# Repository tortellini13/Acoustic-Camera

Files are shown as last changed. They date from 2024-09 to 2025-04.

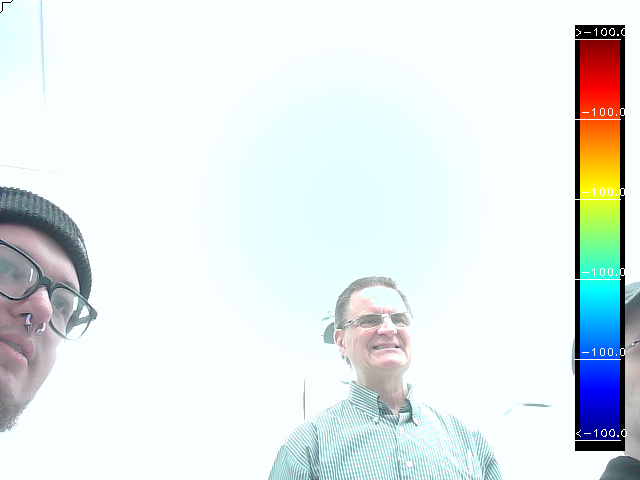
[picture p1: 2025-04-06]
Captures/image_20250403122323.png

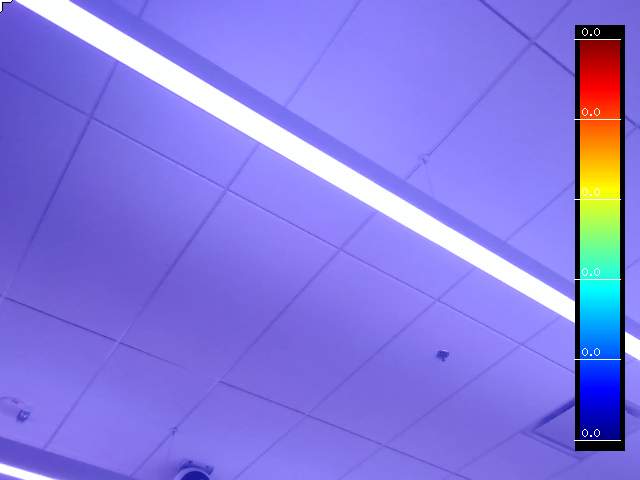
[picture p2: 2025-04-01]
Captures/image_20250327161520.png

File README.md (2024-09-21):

# About the Project
[*Click here to skip to the build*](#the-build)

### The Team
*About us and uhart*  
@us  
*Why did we make this*

### The Project
*What is an acoustical camera*

# How to Build

## Background
We have come across numerous open source projects that assume you know how to do certain basic things going into the project. We aim to eliminate as much of that barrier to entry as possible in the documentation for this project. You should be able to make this project for yourself from scratch with only the skills stated below.

### Skills Required
- thing
- thing

### Dependencies
- thing
- thing

## The Build
### 1. Hardware Required
1. 
2. 
3. 

### 2. Setting Up the Pi

### 3. 3-D Printing

> [!TIP]
> this is a test to see if Tip works.

## Contributing to the Project
This section will help you contribute to the project if you would like to. A bit more prior experience is needed to contribute.

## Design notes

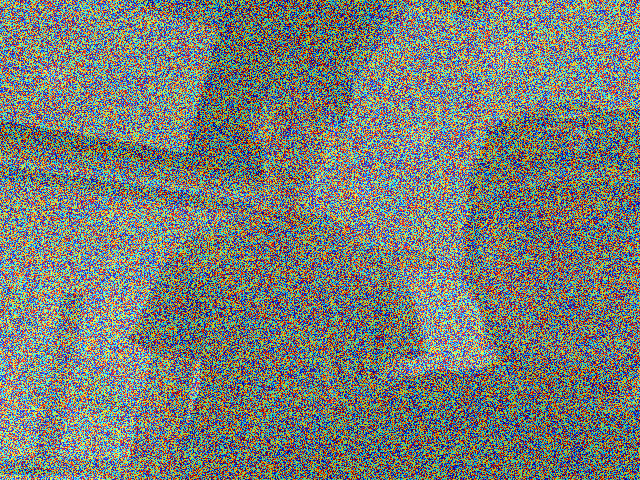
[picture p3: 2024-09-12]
Other/Heat Map Overlay_screenshot_12.09.2024.png

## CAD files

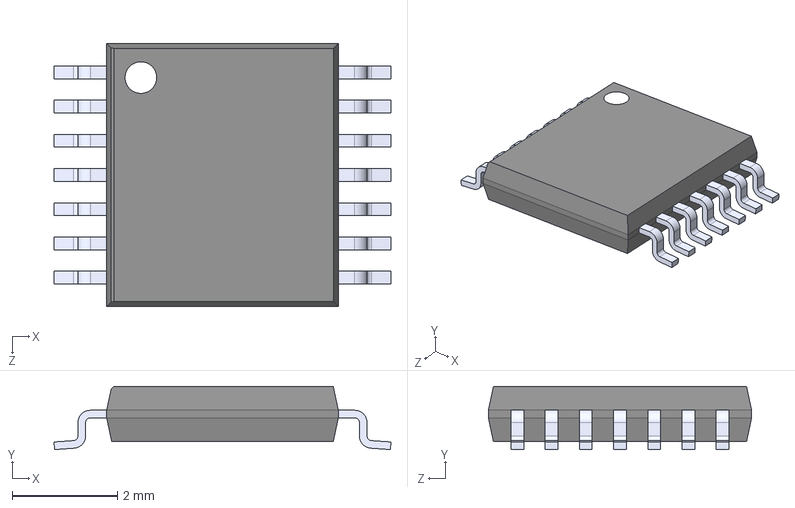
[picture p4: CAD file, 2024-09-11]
Microphone Array CAD/Electrical/Parts (Datasheets, KiCad Libs)/74LCX125MTCX/74LCX125MTCX.step
6.40 x 1.20 x 5.00 mm

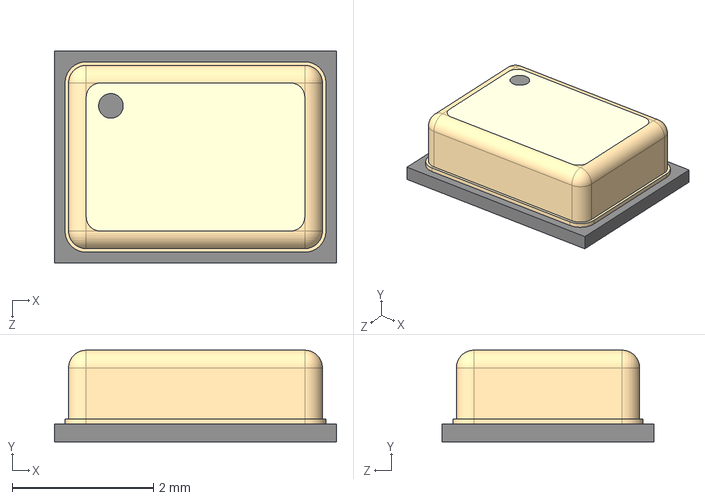
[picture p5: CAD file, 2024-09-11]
Microphone Array CAD/Electrical/Parts (Datasheets, KiCad Libs)/IM69D120V01XTSA1/IM69D120V01XTSA1.step
4.00 x 1.30 x 3.00 mm

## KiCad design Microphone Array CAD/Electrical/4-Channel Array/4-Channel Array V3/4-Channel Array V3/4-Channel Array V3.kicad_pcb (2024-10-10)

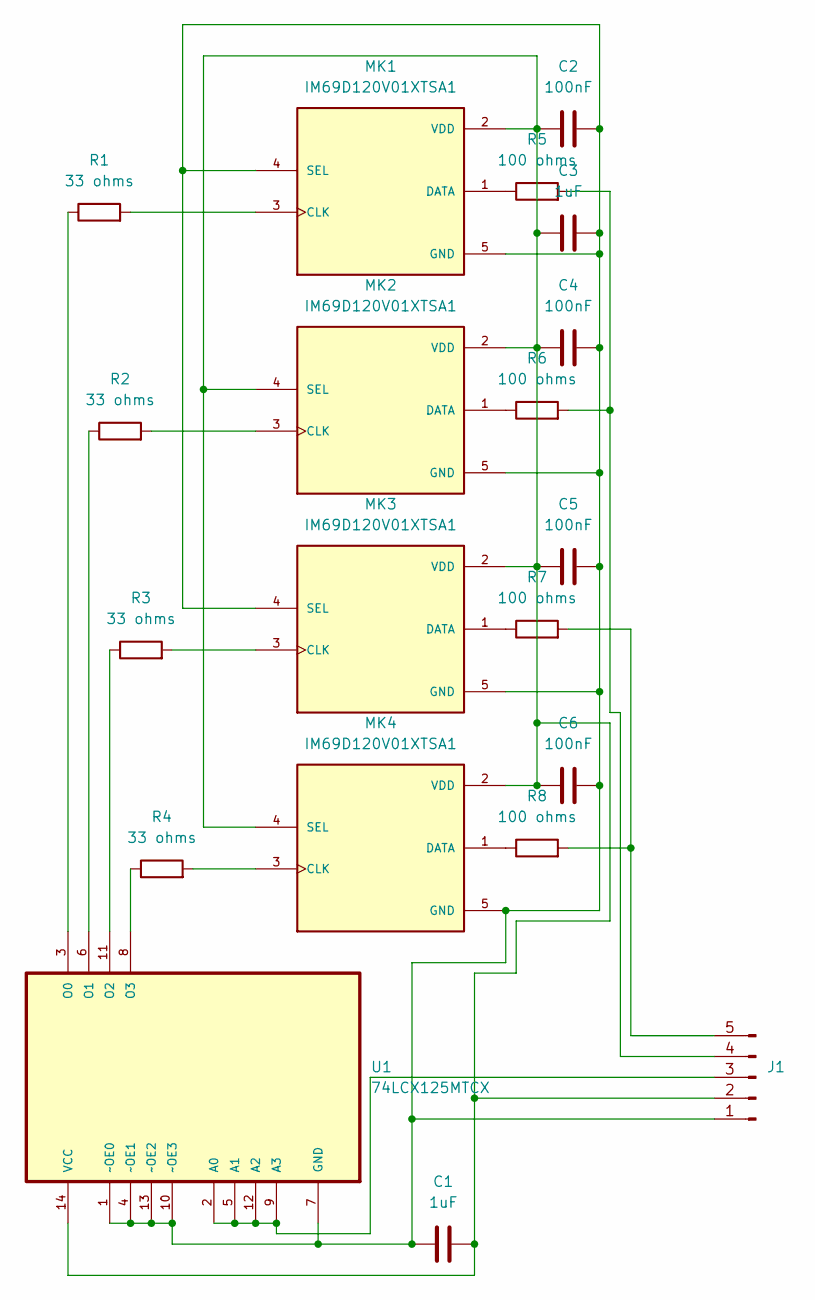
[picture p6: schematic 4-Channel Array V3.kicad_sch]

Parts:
C1, C3: 1uF; R_0603_1608Metric
C2, C4, C5, C6: 100nF; C_0402_1005Metric
J1: Conn_01x05_Pin; JST_XH_B5B-XH-A_1x05_P2.50mm_Vertical
MK1, MK2, MK3, MK4: IM69D120V01XTSA1; XDCR_IM69D120V01XTSA1; PARTREV 1.0
R1, R2, R3, R4: 33 ohms; R_0603_1608Metric
R5, R6, R7, R8: 100 ohms; R_0603_1608Metric
U1: 74LCX125MTCX; SOP65P640X120-14N; MPN 74LCX125MTCX

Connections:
unnamed: C1.1, C2.2, C3.2, C4.2, C5.2, C6.2, J1.1, MK1.4 (SEL), MK1.5 (GND), MK2.5 (GND), MK3.4 (SEL), MK3.5 (GND), MK4.5 (GND), U1.1 (~OE0), U1.4 (~OE1), U1.7 (GND), U1.10 (~OE3), U1.13 (~OE2)
unnamed: C1.2, C2.1, C3.1, C4.1, C5.1, C6.1, J1.2, MK1.2 (VDD), MK2.2 (VDD), MK2.4 (SEL), MK3.2 (VDD), MK4.2 (VDD), MK4.4 (SEL), U1.14 (VCC)
unnamed: J1.3, U1.2 (A0), U1.5 (A1), U1.9 (A3), U1.12 (A2)
unnamed: J1.4, R5.2, R6.2
unnamed: J1.5, R7.2, R8.2
unnamed: MK1.3 (CLK), R1.2
unnamed: MK1.1 (DATA), R5.1
unnamed: MK2.3 (CLK), R2.2
unnamed: MK2.1 (DATA), R6.1
unnamed: MK3.3 (CLK), R3.2
unnamed: MK3.1 (DATA), R7.1
unnamed: MK4.3 (CLK), R4.2
unnamed: MK4.1 (DATA), R8.1
unnamed: R1.1, U1.3 (O0)
unnamed: R2.1, U1.6 (O1)
unnamed: R3.1, U1.11 (O2)
unnamed: R4.1, U1.8 (O3)

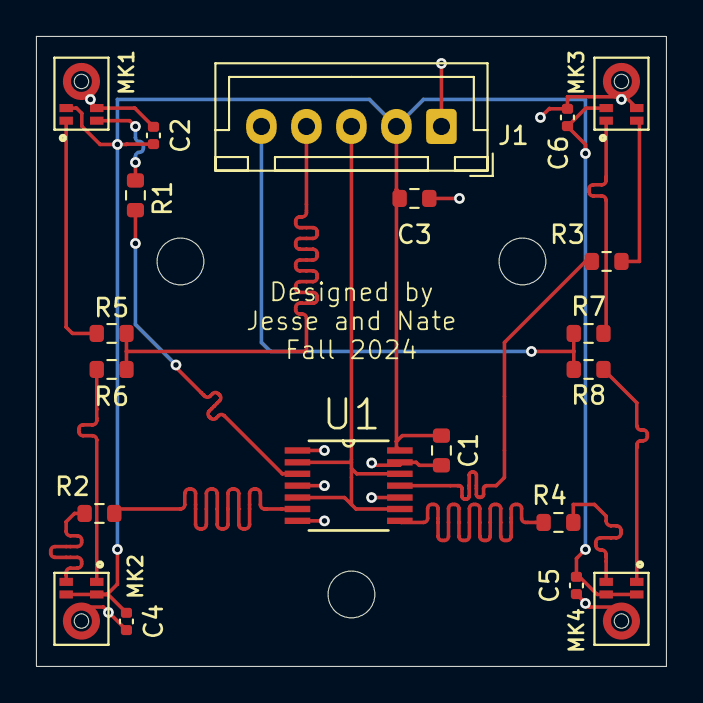
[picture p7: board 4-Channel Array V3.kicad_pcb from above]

Board: 2 copper layers, 35.0 x 35.0 mm, 20 parts (0 on the bottom side), 17 nets.

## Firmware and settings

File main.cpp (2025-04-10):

// Libraries
#include <opencv2/opencv.hpp>
#include <iostream>
#include <vector>
#include <ctime>
#include <chrono>
#include <iomanip>

#include "PARAMS.h"
#include "ALSA.h"
#include "Beamform.h"
#include "Video.h"
#include "Timer.h"
#include "wav.h"


using namespace std;

CONFIG configs(NUM_INT_CONFIGS, NUM_FLOAT_CONFIGS, NUM_BOOL_CONFIGS, NUM_STRING_CONFIGS);

int main()
{

    Mat frame;

    //=====================================================================================

    // Initialize ALSA and Beamform
    #ifdef ENABLE_AUDIO
    #ifdef ENABLE_ALSA
    ALSA ALSA(AUDIO_DEVICE_NAME, M_AMOUNT, N_AMOUNT, SAMPLE_RATE, FFT_SIZE);
    #endif
    beamform beamform(FFT_SIZE, SAMPLE_RATE, M_AMOUNT, N_AMOUNT, NUM_TAPS,
                      MIC_SPACING, 343.0f,
                      MIN_THETA, MAX_THETA, STEP_THETA, NUM_THETA,
                      MIN_PHI, MAX_PHI, STEP_PHI, NUM_PHI);
    #endif

    // Initialize video
    #ifdef ENABLE_VIDEO
    video video(RESOLUTION_WIDTH, RESOLUTION_HEIGHT, FRAME_RATE);
    //VideoCapture cap(0); // Open default camera
    #endif

    //=====================================================================================

    // Timer for testing
    timer test("Test");

    // Arrays to store data
    array3D<float> audio_data_buffer_1(M_AMOUNT, N_AMOUNT, FFT_SIZE);
    array3D<float> audio_data_buffer_2(M_AMOUNT, N_AMOUNT, FFT_SIZE);
    cv::Mat processed_data(NUM_THETA, NUM_PHI, CV_32FC1, cv::Scalar(0));

    // Clear buffers
    for (int m = 0; m < audio_data_buffer_1.dim_1; m++)
    {
        for (int n = 0; n < audio_data_buffer_1.dim_2; n++)
        {
            for (int b = 0; b < audio_data_buffer_1.dim_3; b++)
            {
                audio_data_buffer_1.at(m, n, b) = 0.0f;
                audio_data_buffer_2.at(m, n, b) = 0.0f;
            } // end b
        } // end n
    } // end m

    // Send configuration to ALSA and start recording audio
    #ifdef ENABLE_AUDIO
    #ifdef ENABLE_ALSA
    ALSA.setup();
    ALSA.start();
    #endif
    // cout << "Audio setup complete.\n"; 

    beamform.setup();
    // cout << "Beamform setup complete.\n";

    #ifdef ENABLE_WAV
    WAV WAV;
    WAV.setup("test1k.wav");
    #endif
    #endif
    // Start video capture
    #ifdef ENABLE_VIDEO 
    video.startCapture();
    cout << "Video setup complete.\n";
    #endif
 
    //=====================================================================================

    cout << "Starting main loop.\n";
    while(1)
    {
        
        test.start();
        // Copy data from ring buffer and process beamforming
        #ifdef ENABLE_AUDIO
        #ifdef ENABLE_ALSA
        ALSA.copyRingBuffer(audio_data_buffer_1, audio_data_buffer_2);
        #endif
        // audio_data_buffer_1.print_layer(100);
        #ifdef ENABLE_WAV
        WAV.readWAV(audio_data_buffer_1, audio_data_buffer_2);
        #endif

        beamform.processData(processed_data, 19, 24, POST_dBFS, audio_data_buffer_1, audio_data_buffer_2);
        // cout << "End of processData\n";

        
        #endif
        
        // Generate heatmap and ui then display the frame
        int pcm_error = 0;
        #ifdef ENABLE_VIDEO
        // if (waitKey(1) >= 0) break;
        #ifdef ENABLE_AUDIO
        #ifdef ENABLE_ALSA
        int pcm_error = ALSA.pcm_error;
        #endif
        #endif
        if (video.processFrame(processed_data, pcm_error) == false) break;
        //if (waitKey(1) >= 0) break;
        #endif

        test.end();

        double time = test.time(false);
        double fps = 1 / time;
        // cout << "FPS: " << fps << "\n";

        // test.print();
        // test.print_avg(AVG_SAMPLES);

    } // end loop

    //=====================================================================================

    // Clean up and exit
    #ifdef ENABLE_AUDIO
    #ifdef ENABLE_ALSA
    ALSA.stop();
    #endif
    #endif

    #ifdef ENABLE_VIDEO
    video.stopCapture();
    #endif
 
    return 0;
} // end main

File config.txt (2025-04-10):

=======
third_band_value=25
save_path=/home/pi/Desktop/Acoustic-Camera/Captures
quality=2
full_range=true
imgui_alpha=0.480000
<<<<<<< HEAD
imgui_clamp_max=0
imgui_clamp_min=-93
=======
imgui_clamp_max=20
imgui_clamp_min=-500
>>>>>>> 6685142 (trying phased array again)
heatmap=COLORMAP_JET
hidden_menu=false
mark_max_mag_state=true
octave_bands=false
color_scale_state=true
heat_map_state=true
octave_band_value=6
<<<<<<< HEAD
imgui_threshold=-89
=======
imgui_threshold=-500
>>>>>>> 6685142 (trying phased array again)
static_state=false
data_clamp_state=true
threshold_state=true
auto_save_state=true
record_state=false
capture_image_state=false
random_state=false
options_menu=false

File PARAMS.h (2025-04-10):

#ifndef PARAMS
#define PARAMS

#include "Structs.h"

// Mic channels
#define M_AMOUNT 4 // Amount of mics in the M direction
#define N_AMOUNT 4 // Amount of mics in the N direction
#define MIC_SPACING 0.030f // Meters
const int NUM_CHANNELS = (M_AMOUNT * N_AMOUNT); // Total number of channels
const int CHANNEL_ORDER[M_AMOUNT][N_AMOUNT] =
{
    {10, 8,  2, 0},
    {11, 9,  3, 1},
    {14, 12, 6, 4},
    {15, 13, 7, 5}
};
#define MIC_GAIN 1.0f

// Angles
#define MIN_THETA -30
#define MAX_THETA  30
#define STEP_THETA 3 // 2 is correct
// #define MIN_THETA -90
// #define MAX_THETA 90
// #define STEP_THETA 10
const int NUM_THETA = ((MAX_THETA - MIN_THETA) / STEP_THETA) + 1;

#define MIN_PHI -18
#define MAX_PHI  18
#define STEP_PHI 2 // 1 is correct
// #define MIN_PHI -90
// #define MAX_PHI 90
// #define STEP_PHI 10
const int NUM_PHI = ((MAX_PHI - MIN_PHI) / STEP_PHI) + 1;

#define NUM_TAPS 5

// FFT
#define FFT_SIZE 1024                   // Amount of samples in one frame of the FFT

// Audio
const char* AUDIO_DEVICE_NAME = "hw:1,0"; // arecord -l (type in console to find)
#define SAMPLE_RATE 48000                 // Audio sample rate

// Camera
#define FRAME_RATE 30         // Frame rate of the camera
#define RESOLUTION_WIDTH 640  // Width of the camera
#define RESOLUTION_HEIGHT 480 // Height of the camera

// Heatmap
#define MAP_THRESHOLD_TRACKBAR_VAL 0      // Initial threshold for heat map 
#define MAP_THRESHOLD_OFFSET 100 // Offset for trackbar position relative to threshold value (trackbar pos - offset = threshold)
#define MAP_THRESHOLD_MAX 0  // Maximum threshold for heat map

#define DEFAULT_ALPHA 60       // Default alpha value (ALPHA * 100)

// Text
#define FONT_TYPE FONT_HERSHEY_PLAIN // Font for overlayed text
#define FONT_THICKNESS 1             // Font thickness for overlayed text
#define FONT_SCALE 1                 // Font scale for overlayed text
#define MAX_LABEL_POS_X 10           // Horizontal location of maximum value overlayed text
#define MAX_LABEL_POS_Y 20           // Vertical location of maximum value overlayed text
#define LABEL_PRECISION 1            // Number of decimal places to be shown on screen

// Scale
#define SCALE_WIDTH 40   // Width of the color scale
#define SCALE_HEIGHT 400 // Height of the color scale
#define SCALE_POS_X 580  // X Position of color scale
#define SCALE_POS_Y 40   // Y Position of color scale
#define SCALE_BORDER 5   // Thickness of border around scale
#define SCALE_POINTS 5   // Quantity of points on the scale to be marked`

// Crosshair
#define CROSS_THICKNESS 2 // Thickness for cross at maximum magnitude
#define CROSS_SIZE 20     // Size of cross at maximum magnitude

// FPS counter
#define FPS_COUNTER_AVERAGE 10 // Number of frames to be averaged for calculating FPS

// Post processing types
enum post_processing: uint8_t
{
    POST_dBFS,
    POST_dBZ,
    POST_dBA,
    POST_dBC
};

enum int_configs: uint8_t
{
    imgui_clamp_min,
    imgui_clamp_max,
    imgui_threshold,
    quality,
    octave_band_value,
    third_band_value,
    NUM_INT_CONFIGS
};

enum float_configs: uint8_t
{
    imgui_alpha,
    NUM_FLOAT_CONFIGS
};

enum bool_configs: uint8_t
{
    mark_max_mag_state,
    color_scale_state,
    heat_map_state,
    data_clamp_state,
    threshold_state,

    auto_save_state,
    record_state,
    capture_image_state,

    random_state,
    static_state,

    options_menu,
    hidden_menu,

    full_range,
    octave_bands,
    NUM_BOOL_CONFIGS
};

enum string_configs: uint8_t
{
    heatmap,
    save_path,
    current_band,
    NUM_STRING_CONFIGS
};

enum FULL_OCTAVE_BANDS: uint8_t
{
    FULL_63,
    FULL_125,
    FULL_250,
    FULL_500,
    FULL_1000,
    FULL_2000,
    FULL_4000,
    FULL_8000,
    FULL_16000,
    NUM_FULL_OCTAVE_BANDS
};

enum THIRD_OCTAVE_BANDS: uint8_t
{
    //THIRD_20,
    //THIRD_25,
    //THIRD_31_5,
    //THIRD_40,
    //THIRD_50,
    THIRD_63,
    THIRD_80,
    THIRD_100,
    THIRD_125,
    THIRD_160,
    THIRD_200,
    THIRD_250,
    THIRD_315,
    THIRD_400,
    THIRD_500,
    THIRD_630,
    THIRD_800,
    THIRD_1000,
    THIRD_1250,
    THIRD_1600,
    THIRD_2000,
    THIRD_2500,
    THIRD_3150,
    THIRD_4000,
    THIRD_5000,
    THIRD_6300,
    THIRD_8000,
    THIRD_10000,
    THIRD_12500,
    THIRD_16000,
    //THIRD_20000,
    NUM_THIRD_OCTAVE_BANDS
};

extern CONFIG configs;

// For debugging. Uncomment to enable
// #define PROFILE_MAIN
// #define PROFILE_BEAMFORM
// #define PROFILE_VIDEO
// #define PRINT_AUDIO
// #define PRINT_BEAMFORM
// #define PRINT_FFT
// #define PRINT_FFT_COLLAPSE
// #define PRINT_POST_PROCESS
// #define PRINT_OUTPUT
#define ENABLE_AUDIO
#define ENABLE_VIDEO
#define ENABLE_IMGUI
#define AVG_SAMPLES 10
#define PI_HW // Set for usage on Pi
#define ENABLE_ALSA
// #define ENABLE_WAV
// #define UBUNTU // Set for usage on ubuntu

#endif

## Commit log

2024-09-11 Added Structure for Array Design
    [74LCX125MTCX.step, IM69D120V01XTSA1.step]
2024-09-11 Updated Array PCB
    [4-Channel Array.kicad_pcb, 4-Channel Array.kicad_sch]
2024-09-12 Continued development for Video
    [4-Channel Array.kicad_pcb]
2024-09-12 Continued Array Development
    [4-Channel Array V2.kicad_pcb, 4-Channel Array V2.kicad_sch]
2024-09-19 Array v3
    [4-Channel Array V3.kicad_pcb, 4-Channel Array V3.kicad_sch]
2024-10-10 Added UHart Logo and Fab Files
    [4-Channel Array V3-B_Cu.gbr, 4-Channel Array V3-B_Mask.gbr, 4-Channel Array V3-B_Paste.gbr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]
2024-10-21 Added Max value tracking, fixed annoying trackbar error
    [PARAMS.h]
2024-10-24 Worked on PI. It broke
    [PARAMS.h]
2024-12-04 Attempted frame polling
2024-12-09 Added automatic frame skipping for timing. It is still a mess though
    [PARAMS.h, Video.h]
2024-12-11 Beamforming in frequency doamin. Video multithreaded and different. Some shit still probably broken
    [PARAMS.h, Video.h, Video_before_multithread.h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]
2024-12-21 Reinetgration of video features in progress. Colorbar is still broken
    [PARAMS.h, Video.h]
2024-12-22 Cleaned up video and added more to Timer.h
2024-12-22 Fixed color scale, added FPS, began clamping
    [PARAMS.h, Video.h]
2024-12-23 Added clamping
2025-02-18 FFT is so broken
    [PARAMS.h, Video.h, main.cpp]
2025-02-20 commiting to try and fix this
    [Beamform-buffer slow.h, PARAMS.h]
2025-03-06 Autosave config, added image capture
    [config.txt]
2025-03-06 Update audio device name, modify config settings, and remove unused imgui.ini file
    [config.txt]
2025-03-11 Add initial imgui.ini configuration, adjust processing parameters, and update optimization flags
    [config.txt]
2025-03-13 Continued UI Development
    [config.txt]
2025-03-13 Remove imgui.ini configuration file, enable FFT printing, and refine beamforming calculations
2025-04-01 Small Changes
    [4-Channel Array V3.kicad_sch, config.txt]
2025-04-03 Add configuration for UI windows, update save path, and adjust angle parameters
    [config.txt]
2025-04-08 Artifact gone with new fft
    [config.txt]
2025-04-08 azimuth is screwey
    [config.txt]
2025-04-08 fft is normalized
    [config.txt]
2025-04-10 added wav file reading functionality
    [config.txt]
2025-04-10 trying phased array again
    [config.txt]
